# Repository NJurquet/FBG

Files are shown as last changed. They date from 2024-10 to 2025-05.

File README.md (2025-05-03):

# Fat BOTtomed Girls (FBG) - 2025 Eurobot Project




## Overview

**[Eurobot](https://www.eurobot.org/eurobot-contest/)** is an international robotics competition created in France.
The main goal of this event is to encourage youth to practice robotics with fun, by offering them an unforgettable technical and human experience.

Each year, a new theme is defined and the rules are adapted accordingly, with original actions to perform and a **100% self-made robot to build**.
Robots have to be **autonomous** and must be able to perform various tasks on a playing field in a limited amount of time to gather points.
2 teams play against each other by earning as much points as possible.
Aside from the main robot, teams can build SIMAs (Small Independent Mobile Actuator), which are small autonomous robots only living during the last 15 seconds of the match.

Project management, task sharing, autonomy, team spirit and experimentation are the core values to achieve one’s project and be ready to compete on the D-Day.

The Belgian competition was held in **Mons** and hosted by **[SparkOH!](https://sparkoh.be/projet-robotixs/robotixs/)** on April 19-20, 2025.

Have a look at our **[Wiki](https://github.com/NJurquet/FBG/wiki)** for more details about the project, team, robots, and strategy.

### Theme

The 2025 theme is **The Show Must Go On!**:

> This year the robots want to do even more competitions, more matches for more fun, but this comes with a cost.
> And in order to raise the necessary funds, some big charity concerts are planned: the Robot-Rock-Tour!
> But putting on a show is a lot of work and that’s why the robots are working extra hard to finish the preparations as quickly as possible, so that the show can take place on time.

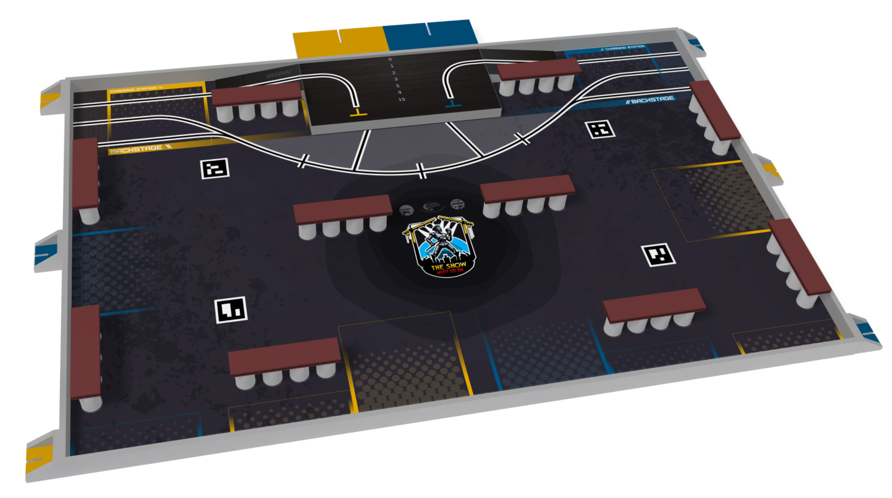
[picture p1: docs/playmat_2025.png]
Playground of the 2025 Eurobot competition


### Points

To score points, the main robot can perform the following actions:

-   **ENSURE THE PROMOTION OF THE SHOW [20 pts]**: Deploy a banner in front of the playground table.
-   **PREPARE THE CONCERT HALL**: Build tribunes of different levels (represented by 1 plank and 2 cans).
    -   [4 pts] per level 1 tribune.
    -   [8 pts] per level 2 tribune.
    -   [16 pts] per level 3 tribune.
-   **STORE TOOLS [10 pts]**: Being in the finishing area at the end of the match.
-   **ESTIMATE THE ENTRIES**: Bonus points earned by displaying an estimated score. The lower the difference between the estimated score and the real score (not counting SIMA score), the more points are earned:

    `Bonus = min(20 points - Delta/2, score done)`

SIMAs can perform the following actions:

-   [5 pts] The superstar is valid on stage at the end of the match.
-   [0, 1, 2, 3, 5, 9 or 15 pts] The superstar is close to the stage edge at the end of the match.
-   [5 pts] For each of the 3 areas of the pit occupied by at least one team groupie at the end of the match.
-   [10 pts] All SIMAs make the party (moving actuator).

## Outcome

### Qualification Round

30 teams participated in the Belgian competition, 15 being from Belgium and 15 from other countries.
The other 15 were from France and Switzerland as guests such that they can test their robots before their national competitions.

The qualification round consist of playing 4 matches against any of the teams and collecting as much cumulative points as possible.

Our team finished **4th out of the 15 Belgian teams** and **7th out of the 30 teams**.
| General Ranking | Belgian Ranking | Team Name | Team Origin | Score |
|---|---|---|---|---|
| 1 | - | Les Karibous | France | 312 |
| 2 | 1 | UCLouvain- Bot save the queen | Belgium | 307 |
| 3 | - | SUDRIABOTIK | France | 304 |
| 4 | 2 | Gramme'N Roll | Belgium | 285 |
| 5 | - | Goldorak | France | 244 |
| 6 | 3 | UCLouvain - WaltiBot | Belgium | 239 |
| **7** | **4** | **ECAM - Fat BOTtomed Girl** | **Belgium** | **238** |
| 7 | - | Coffee Machine | France | 238 |
| 9 | 5 | MonSymphony | Belgium | 235 |
| 10 | 6 | Galil'HELHa | Belgium | 180 |
| 11 | - | Robot ESEO | France | 163 |
| 12 | - | Cybernétique en Nord | France | 158 |
| 13 | - | Evolutek | France | 132 |
| 14 | - | CRENIM | France | 130 |
| 15 | 7 | ECAM - Freddie Carte Mercurie | Belgium | 124 |
| 16 | 8 | Starbot | Belgium | 118 |
| 17 | 9 | ECAM - Johnny Wall-EDay | Belgium | 99 |
| 18 | 10 | ECAM - Daft Bot's | Belgium | 92 |
| 19 | - | RTFM | Switzerland | 73 |
| 20 | - | PM-ROBOTIX | France | 71 |
| 21 | 11 | PAGACH IESN | Belgium | 50 |
| 22 | 12 | UCLouvain - Juke Bot | Belgium | 45 |
| 23 | 13 | UCLouvain - EltonBot | Belgium | 32 |
| 24 | - | TDS-Team Robotique 72 | France | 29 |
| 25 | - | E.S.C.Ro.C.S. | France | 28 |
| 26 | 14 | ECAM - Les Spice Bots | Belgium | 17 |
| 26 | 14 | UCLouvain - GOATBOT | Belgium | 17 |

### Final Round

Being in the top 8 Belgian teams, we made it to the quarter finals.
Our team faced the incredible work of **MonSymphony** who won the championship, ending our journey in the quarter finals.

Result graph of the 2025 Belgium Eurobot competition

## Project

The repository contains the code used for the SIMAs (Superstar & Groupies) in the [SIMA](./SIMA) folder and the code used for the main robot in the [BIG_BOT](./BIG_BOT) folder.

SIMAs were developed using simple `Arduino` components and coded in `C++`/`Arduino`.
The main robot was developed using a Raspberry Pi 4 to control most of the tasks, hardware, and robotic logic in `Python`.

## Installation

### Big Bot

> **Note**: It is assumed that you have a working Raspberry Pi with the OS already installed.

#### Setup & Run

1.  Clone the repository:

    ```bash
    git clone https://github.com/NJurquet/FBG.git
    cd FBG
    ```

2.  Install the Python dependencies:

    ```bash
    pip install -r requirements.txt
    ```

3.  Start the `pigpio` daemon:

    ```bash
    sudo pigpiod
    ```

4.  Run the main program:

    > Make sure every component is connected to the Raspberry Pi GPIO pins before running the program.

    ```bash
    python -m BIG_BOT.src.main --score SOME_SCORE --color YELLOW_OR_BLUE
    ```

    Replace `SOME_SCORE` with the estimated score you want to display on the LCD screen and `YELLOW_OR_BLUE` with the starting color of your robot (either `yellow` or `blue`).

    > The association between components and GPIO pins is defined in the `BIG_BOT/src/config.py` file, feel free to adapt the pins to your needs.

#### Configure Raspberry Pi as hotspot

If you want to use the Raspberry Pi as a hotspot, you will be able to access it remotely via SSH and VNC, and without the need to be connected to a Wi-Fi network (it will create its own access point).
It was especially useful during the competition for running the code on the robot remotely.

**Check [this video](https://youtu.be/TWvL2C95FEg?si=-2T3gCtMyU8DEhau) from Everyday Tech for the whole setup process and explanation.**

> [!NOTE]
> For simplicity and easy access, [RaspAP](https://raspap.com/) is used to configure the Raspberry Pi as a hotspot.
> It provides a web interface for easy configuration. For more details, visit the [RaspAP GitHub repository](https://github.com/RaspAP/raspap-webgui).
>
> If you want more control over the configuration, use `hostapd` and `dnsmasq` to set up the hotspot manually.

> [!IMPORTANT]  
> **To be able to connect the hotspot to a Wi-Fi network, you will need to have a USB Wi-Fi dongle / adapter** so the Raspberry can use its built-in Wi-Fi interface `wlan0` as the one to connect to the network and the one provided by the USB dongle `wlan1` as the hotspot.

Most of the steps are explained in the RaspAP documentation and GitHub.

1.  First, update RPi OS to its latest version, including the kernel and firmware, followed by a reboot.

    ```bash
    sudo apt-get update
    sudo apt-get full-upgrade
    sudo reboot
    ```

2.  Set the WiFi country where you plan to use the Raspberry in raspi-config's `Localisation Options`.

    ```bash
    sudo raspi-config
    ```

    > You can also enable SSH and VNC in the `Interfacing Options` menu.

3.  Install RaspAP:

    ```bash
    curl -sL https://install.raspap.com | bash
    ```

    > Note that several options to install with RaspAP will be proposed. We declined all of them as we did not need VPN, ad block or WireGuard, feel free to install them if you want.

4.  Reboot the Raspberry Pi.

    ```bash
    sudo reboot
    ```

You should now see a new Wi-Fi network called `raspi-webgui` in your available networks with this configuration:

-   **SSID**: raspi-webgui
-   **Password**: ChangeMe
-   **IP address**: 10.3.141.1
-   **DHCP range**: 10.3.141.50 — 10.3.141.254

Now you can plug the USB Wi-Fi dongle into the Raspberry Pi and check if it is recognized by the system:

```bash
lsusb
```

> [!NOTE]
> You might need to install the driver for your USB Wi-Fi dongle if it is not recognized by the system.
> Check the manufacturer's website for the driver and installation instructions.
> The best is to use a Linux compatible USB Wi-Fi dongle so this process can be skipped.

You should see the new WLAN interface `wlan1` not connected to anything and the `wlan0` used for the hotspot with:

```bash
ifconfig
```

The admin web interface can be accessed by entering the Raspberry IP address `10.3.141.1` or using its hostname `raspberrypi.local` in your web browser.
The default credentials are:

-   **Username**: admin
-   **Password**: secret

Make sure to change the default SSID and password in the `Basic` & `Security` tabs of the hotspot web interface, as well as the country code in the `Advanced` tab to the one set with `raspi-config`.

Then, in the `RaspAP` web interface, go to the `Hotspot` tab and change the interface from `wlan0` to `wlan1`, then click on `Save`.

In the Raspberry terminal, modify the `/etc/dhcpcd.conf` file by removing the the `wlan0` part so that it only uses the `wlan1` interface for the hotspot (the IP address assigned to the new `wlan1` is `10.9.141.1`):

```bash
sudo nano /etc/dhcpcd.conf
```

And remove the previous network preconfigurations with:

```bash
sudo rm /etc/NetworkManager/system-connections/preconfigured.nmconnection
sudo reboot
```

Now connect to the new hotspot and you should be able to access the web interface with correct WLANs.
Go to the `Wi-Fi client` tab to connect the `wlan0` interface to a Wi-Fi network.

> [!TIP]
> If you encounter connection or interface issues, try restarting the hotspot in the `Hotspot` tab.

### SIMA

1.  Install the Arduino IDE from the official website: [Arduino IDE](https://www.arduino.cc/en/software).

2.  Open the Arduino IDE and install the required libraries for the SIMA code:

    -   `Servo`: [link](https://docs.arduino.cc/libraries/servo/)
    -   `Adafruit Motor Shield V2 Library`: [link](https://github.com/adafruit/Adafruit_Motor_Shield_V2_Library)

3.  Adapt the pins and `groupie` & `topStartLine` configuration constants in the `SIMA/SIMA/SIMA.ino` file to your SIMA, then upload the code to your Arduino board.

    ```cpp
    // CONFIGURATION CONSTANTS ///////////////////////
    const bool groupie = true;
    const bool leftStart = digitalRead(startLeftPin);
    const bool topStartLine = false;
    const int zoneNumber = topStartLine ? 1 : 2;
    //////////////////////////////////////////////////
    ```

## License

This project is licensed under the MIT License.

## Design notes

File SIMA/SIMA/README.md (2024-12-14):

# Superstar & Groupies

## Overview

The superstar and groupies are Small Independent Mobile Actuators (SIMA) capable of navigating its environment while avoiding obstacles. They both have specific roles but they use an ultrasonic sensor to detect obstacles, IR sensors to follow lines drawn on the table, Bluetooth module for remote debugging and a finite state machine (FSM) to manage its states and behaviors.

## Depedencies

-   `Adafruit Motor Shield V2 Library` : v1.1.3

## Components

-   **Arduino Uno**: The microcontroller used to control the robot.
-   **Adafruit Motor Shield V2**: Used to control the motors of the robot.
-   **Ultrasonic Sensor HC-SR04**: Used to detect obstacles in the robot's path.
-   **IR sensor**: Used to follow lines drawn on the table.
-   **HC-05 Bluetooth module** : Used to debug robot actions.

## Setup

### Hardware Setup

-   **Motors** : First, place the motor shield on the Arduino. Then, connect the left motor to `M4`, and the right motor to `M3`.
-   **Ultrasonic sensor** : Connect the VCC to `5V`, GND to `GND`, Trig to pin `11`, and Echo to pin `12`.
-   **IR sensors** : Connect the VCC to `5V`, GND to `GND`, and the left sensor to pin `A0` and the right sensor to pin `A1`.
-   **Bluetooth** : Connect the VCC to `5V`, GND to `GND`, RX to pin `10`, and TX to pin `9`.

### Software Setup

-   Open Arduino IDE and install the necessary libraries (e.g., Adafruit Motor Shield V2 library).
-   Open the `.ino` file (`.cpp` and `.h` files should open automatically).
-   Build & upload the code to the Arduino.

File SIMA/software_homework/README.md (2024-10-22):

# Superstar & Groupies

## Overview

The superstar and groupies are Small Independent Mobile Actuators (SIMA) capable of navigating its environment while avoiding obstacles. They both have specific roles but they use an ultrasonic sensor to detect obstacles, IR sensors to follow lines drawn on the table and a finite state machine (FSM) to manage its states and behaviors.

## Depedencies

-   `Adafruit Motor Shield V2 Library`

## Components

-   **Arduino Uno**: The microcontroller used to control the robot.
-   **Adafruit Motor Shield V2**: Used to control the motors of the robot.
-   **Ultrasonic Sensor HC-SR04**: Used to detect obstacles in the robot's path.
-   **IR sensor**: Used to follow lines drawn on the table.

## Setup

1. **Hardware Setup**:

    - Connect the ultrasonic sensor to the specified pins on the Arduino.
    - Connect the IR sensors to the specified pins on the Arduino.
    - Connect the motors to the Adafruit Motor Shield V2.
    - Attach the Motor Shield to the Arduino.

2. **Software Setup**:
    - Install the necessary libraries (e.g., Adafruit Motor Shield library).
    - Build & upload the code to the Arduino.

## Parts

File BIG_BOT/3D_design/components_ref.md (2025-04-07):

# Big Bot Assembly

This is a description of the components used for the **Big Bot** project, including the motor, sensors, and accessories.

## Components

### 1. **Servo Motor: MG996R**
The **MG996R** is a high-torque servo motor, suitable for precise control in various robotic applications. It provides powerful rotation, ideal for applications requiring motion and positioning.

### 2. **Emergency Button: A01ES-DM + A0154B-D + A01YL1**
The **A01ES-DM** emergency button system allows for quick and reliable activation of emergency stops in critical applications. It ensures safety in the event of a failure or unexpected behavior in the system.

### 3. **Aluminum Profiles: MakerBeamXL - 15x15mm**
These aluminum profiles are used for the structural framework of the bot. With the **MakerBeamXL** 15x15mm profiles, you get a lightweight, durable, and customizable structure that is easy to assemble.

### 4. **Raspberry Pi 4**
The **Raspberry Pi 4** serves as the brain of the Big Bot. With its quad-core processor, powerful GPU, and ample RAM, the Raspberry Pi 4 can handle a variety of robotic tasks, from control to data processing.

### 5. **12V Motors: 37D Metal Gearmotors**
The **37D Metal Gearmotors** are robust motors perfect for driving the movement of the bot. With their durable metal gears and high torque, these motors can drive heavy loads and work reliably in various robotic setups.

### 6. **Ultrasonic Sensors: HC-SR04**
The **HC-SR04** ultrasonic sensors provide precise distance measurements, helping the bot navigate its environment. With its simple interface and accurate range, it's a perfect sensor for obstacle detection and avoidance.

### 7. **Ball Caster: LEZED L176**
The **LEZED L176** ball caster is a small but essential part of the Big Bot, providing a stable rolling point for easy movement. It ensures smooth navigation and stability for mobile robots.

### 8. **LCD Display: AZDelivery HD44780 2004**
The **AZDelivery HD44780 2004** LCD display is used for showing important information and status updates. With its clear, readable display, it serves as an interface for diagnostics and control feedback.

### 9. **DC-DC Step Down Buck Converter: AZDelivery XL4016E1**
The **AZDelivery XL4016E1** step-down buck converter allows for efficient voltage conversion. It steps down the input voltage (from 12V to 5V) to power the Raspberry Pi and other components of the Big Bot.

### 10. **3D-Printed Parts**
In addition to the listed components, several parts of the **Big Bot** were 3D-printed for custom structures, mounting solutions, and other specialized components. These parts help reduce weight and offer a high degree of customization.

## Conclusion

This is the collection of key components that form the **Big Bot**. Each part plays a crucial role in ensuring functionality, reliability, and ease of customization. Whether for movement, sensing, or interaction, these components work together to bring the robot to life.

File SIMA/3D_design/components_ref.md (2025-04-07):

# Super Star & Groupies Bots Assembly

This document outlines the components used in the **Super Star** and **Groupies Bots** projects, covering motors, sensors, and other essential accessories.

## Components

### 1. **Emergency Button: A01ES-DM + A0154B-D + A01YL1**
The **A01ES-DM** emergency button system ensures quick and reliable activation of emergency stops in critical applications. It provides an essential safety feature for the bot, preventing malfunction or unexpected behavior by enabling immediate system shutdown.

### 2. **Ultrasonic Sensors: HC-SR04**
The **HC-SR04** ultrasonic sensors are crucial for measuring distances and enabling the bots to navigate their surroundings. With their easy integration and accurate range, these sensors are perfect for obstacle detection and avoidance.

### 3. **3D-Printed Parts**
Several parts of the **Super Star** and **Groupies Bots** were 3D-printed to meet specific design requirements. These custom structures, mounting solutions, and other components offer reduced weight, greater flexibility, and enhanced customization options.

### 4. **IR Sensor: Frienda-Obstacle-431S**
The **Frienda-Obstacle-431S** infrared sensor aids in detecting obstacles around the bot by emitting infrared light and measuring the reflection. This sensor is ideal for proximity sensing and works well in conjunction with the ultrasonic sensors to improve navigation and decision-making.

### 5. **Servo Motor: MS18**
The **MS18** servo motor provides high precision and reliable movement for the **Super Star** and **Groupies Bots**. It's designed to deliver smooth motion and control in applications where accuracy and positioning are essential.

### 6. **Arduino Uno**
The **Arduino Uno** acts as the central controller for both the **Super Star** and **Groupies Bots**. With its open-source platform, the Arduino Uno is perfect for prototyping and programming, offering a simple yet powerful foundation for building and controlling robots.

### 7. **DFRobot MiniQ 2WD - 2 Wheel Robot Chassis with DC Motor Drive**
The **DFRobot MiniQ 2WD** chassis is designed for building compact two-wheel-drive robots. It's equipped with DC motors, making it ideal for mobile robots that require agile movement and easy control. The chassis provides a solid foundation for building both the **Super Star** and **Groupies Bots**.

### 8. **Feetech FT-DC-002-KIT - Aluminium 2WD Robot Chassis**
The **Feetech FT-DC-002-KIT** is another two-wheel-drive chassis used in the **Groupies Bots** project. Constructed from durable aluminum, this chassis offers lightweight performance while maintaining strength, making it a perfect platform for building versatile robots.

## Conclusion

The **Super Star** and **Groupies Bots** are assembled from a carefully selected set of components, each chosen for its functionality, durability, and compatibility. Whether for movement, sensing, or interaction, these parts come together to create highly adaptable and customizable robots ready to take on any challenge.

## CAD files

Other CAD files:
SIMA/3D_design/super_star/assembly/assembly_super_star.step
SIMA/3D_design/groupie/stl/emergency_button_holder_mainpart.step
BIG_BOT/3D_design/assembly/big_bot.step
BIG_BOT/3D_design/stl/lcd_frame.stl
SIMA/3D_design/groupie/assembly/groupie.step
SIMA/3D_design/groupie/stl/emergency_button_holder_subpart.step
SIMA/3D_design/super_star/stl/capot_cover.step
BIG_BOT/3D_design/stl/caster_holder.stl
SIMA/3D_design/super_star/stl/ultrasonic_ir_sensors_holder.step
BIG_BOT/3D_design/stl/foldable_fork.stl
SIMA/3D_design/groupie/stl/carrosserie.step
SIMA/3D_design/super_star/stl/servo_celebration_module.step
BIG_BOT/3D_design/stl/side_claw_servo_structure.stl
SIMA/3D_design/groupie/stl/battery_holder.step
SIMA/3D_design/super_star/stl/carrosserie.step
BIG_BOT/3D_design/stl/center_claw.stl
SIMA/3D_design/groupie/stl/upper_chassis.step
SIMA/3D_design/super_star/stl/upper_chassis.step
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

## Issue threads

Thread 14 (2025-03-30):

Bug: gpiozero.DistanceSensor Blocking Code with DistanceSensorNoEcho Warning

NJurquet, 2025-03-30:
### Bug Description
When trying to get the distance with `gpiozero.DistanceSensor` as an HC-SR04 ultrasonic sensor, the warning `warnings.warn(DistanceSensorNoEcho('no echo received'))` appears. This warning seems to block further execution of the code.
We have used a Raspberry Pi 4B running on `Python 3.12`.
Interestingly, all unit tests using Mocks pass without issues, meaning the problem only occurs with actual hardware.
Bug is most problably due to #13 PR.

### Steps to Reproduce
1. Connect an HC-SR04 ultrasonic sensor to a Raspberry Pi with trigger and echo pin connected. Echo placed in a voltage divider.
2. Initialize the `DistanceSensor` in a Python script using `gpiozero`.
3. Attempt to read the distance measurement with `DistanceSensor.distance`.
4. Run script

### Expected Behavior
- The `DistanceSensor` should return the distance.
- The warning should be non-blocking and allow the rest of the script to continue running even if no echo is received.

### Actual Problem
The following code triggers the issue:

```python
# ultrasonicSensor.py
class UltrasonicSensor:
    def getDistance(self) -> float:
        """
        Returns the distance measured in centimeters.

        Returns:
            float: The distance in centimeters.
        """
        return self._sensor.distance * 100

# ultrasonicController.py
class UltrasonicController:
    def add_sensor(self, pos: USPosition, echoPin: int, trigPin: int) -> None:
        """
        Add a new ultrasonic sensor to the controller.

        Parameters:
            `pos` (USPosition): The position of the sensor.
            `echoPin` (int): The GPIO pin connected to the sensor's echo pin.
            `trigPin` (int): The GPIO pin connected to the sensor's trigger pin.
        """
        ...

        if any(sensor.pos == pos for sensor in self._sensors):
            raise ValueError(f"Sensor with position {pos} already exists in the controller.")
        self._sensors.append(UltrasonicSensor(pos, echoPin, trigPin))

# robot.py
class Robot:
    def __init__(self):
        self.ultrasonicController = UltrasonicController()
        self.ultrasonicController.add_sensor(USPosition.FRONT_RIGHT, US_FRONT_RIGHT_ECHO_PIN, US_FRONT_RIGHT_TRIG_PIN)
        self.ultrasonicController.add_sensor(USPosition.FRONT_LEFT, US_FRONT_LEFT_ECHO_PIN, US_FRONT_LEFT_TRIG_PIN)

# config.py
## Ultrasonic Sensors Pins ##
US_FRONT_RIGHT_TRIG_PIN = 7
US_FRONT_RIGHT_ECHO_PIN = 8

US_FRONT_LEFT_TRIG_PIN = 20
US_FRONT_LEFT_ECHO_PIN = 21
```
Output:
```
/usr/lib/python3/dist-packages/gpiozero/input_devices.py:1382: DistanceSensorNoEcho: no echo received
  warnings.warn(DistanceSensorNoEcho('no echo received'))
```

### Additional notes
- The issue occurs in real hardware but does not appear in unit tests using Mocks.
- It is unclear whether this is a bug in software or related to hardware like the voltage divider.

NJurquet, 2025-03-31:
Everything mentionned in this comment was commited on the `sprint_2` branch.

### DistanceSensorNoEcho warning
I've just tested the ultrasonic sensors by connecting correct pins to the Raspberry and everything was working correctly when running `ultrasonicController` or `ultrasonicSensor` except that the distance is wrong.
```python
# ultrasonicSensor.py
if __name__ == "__main__":
    import time
    us_sensor = UltrasonicSensor(USPosition.FRONT_RIGHT, 7, 8)
    while True:
        print(f"Distance: {us_sensor.getDistance():.2f} cm")
        time.sleep(1)
```

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
I've tested the same sensor on an Arduino and same result so this sensor is actually deficient.

Also when removing the trigger or echo pin from the Raspberry, the `no echo received` warning was thrown:
```
/home/ecam/.local/lib/python3.12/site-packages/gpiozero/input_devices.py:975: DistanceSensorNoEcho: no echo received
  warnings.warn(DistanceSensorNoEcho('no echo received'))
```
This **echo problem is still blocking execution of the code** even when catching warnings with `with warnings.catch_warnings()` and `warnings.simplefilter("ignore")` as the warning is only a "print". I couldn't find any solution for this except from not having that warning by having all working hardware.

**So this issue is a *hardware* problem most certainly cause by wrong wiring, short-circuits or voltage divider on echo pin.**

### PWMSoftwareFallback warning
When using the default pin factory for the ultrasonic sensor, it always give a warning that we should use `pigpio` and that this library is more accurate:
```
/home/ecam/.local/lib/python3.12/site-packages/gpiozero/input_devices.py:852: PWMSoftwareFallback: For more accurate readings, use the pigpio pin factory.See https://gpiozero.readthedocs.io/en/stable/api_input.html#distancesensor-hc-sr04 for more info
  warnings.warn(PWMSoftwareFallback(
```
So I've added the `PiGPIOFactory` as the factory to use and works perfectly. **Note that it required to run `sudo pigpiod` to start the daemon with root privileges**.

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

I've also managed problems occuring when we are testing the code on Windows or when runing tests on GitHub Actions by using dynamic import of the factory. `pigpio` is only working on Raspberry, so if we are running the project in another OS / environment, it will use the default pin factory that was working before.
```python
# ultrasonicSensor.py
import os
import platform
from gpiozero import DistanceSensor, Pin
if os.getenv("GITHUB_ACTIONS") == "true" or platform.system() == "Windows":
    factory = None
else:
    try:
        from gpiozero.pins.pigpio import PiGPIOFactory
        factory = PiGPIOFactory()
    except OSError:
        factory = None
from ..constants import USPosition

...

    def __init__(self, pos: USPosition, echoPin: int, trigPin: int):
        self._sensor = DistanceSensor(echo=echoPin, trigger=trigPin, max_distance=1, pin_factory=factory)
```

NJurquet, 2025-04-01:
So I confirm ultrasonic sensors are working, as well as the ultrasonic controller code. I've connected the trigger/echo pins to the same pins defined in `config.py` (which were the same used during sprint 2).

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

Distances measured are of correct values and the event triggered is working well : No event when distances < 20cm, obstacle detected when detecting a new one, and obstacle present when continuously detecting the same obstacle.

As it works as intended I close this issue.

Closed 2025-04-01.

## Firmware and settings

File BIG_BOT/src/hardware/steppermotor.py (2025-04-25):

from gpiozero import DigitalOutputDevice, Button
from ..utils import precise_sleep


class StepperMotor:
    """
    Interfaces with a NEMA stepper via an A4988 driver.

    The following pins are used:
      - step: pulses for each step.
      - dir: controls direction (clockwise or counter-clockwise).
      - MS1, MS2, MS3: define the microstepping resolution.

    Limit switches:
      - Optionally, you can provide top_limit_pin and bottom_limit_pin.
        These are used for homing and safe operation to stop rotation
        when a mechanical limit is reached.

    Microstepping settings supported (resolution: multiplier):
      - 1    → Full step    (MS1=LOW, MS2=LOW, MS3=LOW)    → 200 steps/rev
      - 1/2  → Half step    (MS1=HIGH, MS2=LOW, MS3=LOW)   → 400 steps/rev
      - 1/4  → Quarter step (MS1=LOW, MS2=HIGH, MS3=LOW)   → 800 steps/rev
      - 1/8  → Eighth step  (MS1=HIGH, MS2=HIGH, MS3=LOW)  → 1600 steps/rev
      - 1/16 → Sixteenth    (MS1=HIGH, MS2=HIGH, MS3=HIGH) → 3200 steps/rev (if supported)

    A simple position tracking (in steps) is implemented so that after homing the vertical position can be monitored and controlled.

    **Note:** The reset and sleep pins on your A4988 are assumed to be wired together to keep the stepper motor at full power.
    """

    # Microstepping mapping: resolution → (MS1, MS2, MS3)
    _MICROSTEP_RESOLUTION = {
        1:  (0, 0, 0),
        2:  (1, 0, 0),
        4:  (0, 1, 0),
        8:  (1, 1, 0),
        16: (1, 1, 1),
    }
    _BASE_STEPS_PER_REV = 200  # Full step base (1.8° per step)

    def __init__(self, step: int, dir: int, ms1: int, ms2: int, ms3: int,
                 step_delay: float = 0.002, microstep: int = 1,
                 top_limit_pin: int | None = None, bottom_limit_pin: int | None = None):
        """
        Initialize the stepper motor and, optionally, limit switches.

        Parameters:
            `step` (int):   GPIO pin for STEP.
            `dir` (int):    GPIO pin for DIR.
            `ms1` (int):  GPIO pin for MS1.
            `ms2` (int):  GPIO pin for MS2.
            `ms3` (int):  GPIO pin for MS3.
            `step_delay` (float): Delay between high and low transitions (in seconds), default is 0.002s. Step delay must be higher or equal to 0.002s.
            `microstep` (int): Number of microsteps to perform per full step, default is 1. The corresponding microstepping resolution is (1, 1/2, 1/4, 1/8, 1/16).
            `top_limit_pin` (int): Optional GPIO pin for the top limit switch, default is None.
            `bottom_limit_pin` (int): Optional GPIO pin for the bottom limit switch, default is None.
        """
        # Create gpiozero devices for A4988 control.
        self._step_device = DigitalOutputDevice(step)
        self._dir_device = DigitalOutputDevice(dir)
        self._ms1_device = DigitalOutputDevice(ms1)
        self._ms2_device = DigitalOutputDevice(ms2)
        self._ms3_device = DigitalOutputDevice(ms3)
        try:
            self._top_switch = Button(top_limit_pin) if top_limit_pin is not None else None
            self._bottom_switch = Button(bottom_limit_pin) if bottom_limit_pin is not None else None
        except ValueError as e:
            self._top_switch = None
            self._bottom_switch = None
            import warnings
            warnings.warn(f"Top or bottom limit switches are invalid or not connected.\nError: {e}", stacklevel=2)
        precise_sleep(0.001)

        if step_delay < 0.002:
            raise ValueError("step_delay must be >= 0.002 seconds.")
        self._step_delay = step_delay
        self._current_resolution = microstep
        self._steps_per_rev = self._BASE_STEPS_PER_REV * microstep
        self.set_microstepping(self._current_resolution)

        self.current_position: int | None = None  # Vertical position in steps (None until homed).

        self.stop_flag = False  # Call this Flag to stop the motor.

    def set_microstepping(self, resolution: int) -> None:
        """
        Set the microstepping resolution to apply on MS1, MS2, MS3 pins.

        Parameters:
            `resolution` (int): The resolution to set, one of (1, 2, 4, 8, 16).
                - 1: Full step (200 steps/rev).
                - 2: Half step (400 steps/rev).
                - 4: Quarter step (800 steps/rev).
                - 8: Eighth step (1600 steps/rev).
                - 16: Sixteenth step (3200 steps/rev).
        Raises:
            `ValueError`: If the resolution is unsupported.
        """
        if resolution not in self._MICROSTEP_RESOLUTION:
            raise ValueError(f"Unsupported resolution: {resolution}. Choose from {list(self._MICROSTEP_RESOLUTION.keys())}")
        ms1_state, ms2_state, ms3_state = self._MICROSTEP_RESOLUTION[resolution]
        self._ms1_device.on() if ms1_state else self._ms1_device.off()
        self._ms2_device.on() if ms2_state else self._ms2_device.off()
        self._ms3_device.on() if ms3_state else self._ms3_device.off()
        self._current_resolution = resolution
        self._steps_per_rev = self._BASE_STEPS_PER_REV * resolution

    @property
    def steps_per_rev(self) -> int:
        """Return the full number of steps per revolution, including the current microstepping resolution."""
        return self._steps_per_rev

    def step(self, steps: int, clockwise: bool = False, update_position: bool = True) -> None:
        """
        Pulse the STEP pin a specific number of times to rotate the motor by a given number of steps.
        The direction is controlled by the DIR pin.

        Parameters:
            `steps` (int): Number of steps to move (absolute count).
            `clockwise` (bool): Direction flag, default is False. Clockwise rotation increases vertical position.
            `update_position` (bool): If True and if current_position is set, update the internal position count.
        """
        self._dir_device.value = clockwise  # Set direction.
        for _ in range(abs(steps)):
            if self.stop_flag:
                print("Stepper Motor stopped.")
                break

            self._step_device.on()
            precise_sleep(self._step_delay)  # Precise sleep to avoid timing issues.
            self._step_device.off()
            precise_sleep(self._step_delay)  # Precise sleep to avoid timing issues.
            if update_position and self.current_position is not None:
                self.current_position += 1 if clockwise else -1

    def rotate(self, rotations: float, clockwise: bool = True) -> None:
        """
        Rotate the motor a specific number of rotations (full or fractional).

        Parameters:
            `rotations` (float): Number of full or fractional rotations.
            `clockwise` (bool): Direction of rotation, default is True. Clockwise rotation increases vertical position.
        """
        total_steps = int(self._steps_per_rev * rotations)
        print(f"Rotating {rotations} rotations ({total_steps} steps) {'clockwise' if clockwise else 'counter-clockwise'}.")
        self.step(total_steps, clockwise=clockwise, update_position=True)

    def home_bottom(self) -> None:
        """
        Move the motor downward until the bottom limit switch is triggered.
        After homing, the vertical position is set to 0.

        Raises:
            `Exception`: If the bottom limit switch is not configured.
        """
        if self._bottom_switch is None:
            raise Exception("Bottom limit switch not configured.")
        while not self._bottom_switch.is_active:
            if self.stop_flag:
                print("Stepper Motor stopped.")
                break

            self.step(1, clockwise=False, update_position=False)
        self.current_position = 0
        print("Homed: bottom limit reached. Current position set to 0.")

    def move_to_top(self) -> None:
        """
        Step upward one step at a time until the top limit switch is activated.
        Updates the current position as it moves.

        Raises:
            `Exception`: If the top limit switch is not configured.
        """
        if self._top_switch is None:
            raise Exception("Top limit switch not configured.")
        while not self._top_switch.is_active:
            if self.stop_flag:
                print("Stepper Motor stopped.")
                break

            self.step(1, clockwise=True, update_position=True)
        print("Reached top limit.")

    def move_to_bottom(self):
        """
        Step downward one step at a time until the bottom limit switch is activated.
        Updates the current position as it moves.

        Raises:
            `Exception`: If the bottom limit switch is not configured.
        """
        if self._bottom_switch is None:
            raise Exception("Bottom limit switch not configured.")
        while not self._bottom_switch.is_active:
            if self.stop_flag:
                print("Stepper Motor stopped.")
                break

            self.step(1, clockwise=False, update_position=True)
        print("Reached bottom limit.")
        self.current_position = 0

    def move_to_position(self, target_position: int) -> None:
        """
        Move the motor one step at a time to a target vertical position.
        Current position is tracked in steps. It is assumed that the motor has been homed,
        so current_position is not None.

        Parameters:
            `target_position` (int): The desired vertical position in step counts.

        Raises:
            `Exception`: If current_position is undefined (None).
        """
        if self.current_position is None:
            raise Exception("Current position is undefined. Please home the motor first.")

        print(f"Moving from position {self.current_position} to target {target_position}.")
        while abs(self.current_position - target_position) > 0:
            if self.stop_flag:
                print("Stepper Motor stopped.")
                break

            # If going upward, check if top limit is reached.
            if self.current_position < target_position:
                if self._top_switch is not None and self._top_switch.is_active:
                    print("Top limit reached; cannot move further upward.")
                    break
                self.step(1, clockwise=True, update_position=True)
            # If going downward, check if bottom limit is reached.
            elif self.current_position > target_position:
                if self._bottom_switch is not None and self._bottom_switch.is_active:
                    print("Bottom limit reached; cannot move further downward.")
                    break
                self.step(1, clockwise=False, update_position=True)
        print(f"Target reached. Current position: {self.current_position}")

    def cleanup(self) -> None:
        """
        Clean up all gpiozero stepper devices.
        """
        self._step_device.close()
        self._dir_device.close()
        self._ms1_device.close()
        self._ms2_device.close()
        self._ms3_device.close()
        if self._top_switch:
            self._top_switch.close()
        if self._bottom_switch:
            self._bottom_switch.close()

    def stop(self) -> None:
        """
        Stop the motor immediately by setting the stop flag.
        """
        self.stop_flag = True
        print("Stepper Motor stop flag set.")


if __name__ == '__main__':
    from ..config import STEPPER_DIR_PIN, STEPPER_STEP_PIN, STEPPER_MS1_PIN, STEPPER_MS2_PIN, STEPPER_MS3_PIN, STEPPER_BOTTOM_LIMIT_PIN, STEPPER_TOP_LIMIT_PIN
    from gpiozero import Device
    from gpiozero.pins.mock import MockFactory
    Device.pin_factory = MockFactory()

    stepper = StepperMotor(step=STEPPER_STEP_PIN, dir=STEPPER_DIR_PIN,
                           ms1=STEPPER_MS1_PIN, ms2=STEPPER_MS2_PIN, ms3=STEPPER_MS3_PIN,
                           step_delay=0.005, microstep=1,
                           top_limit_pin=STEPPER_TOP_LIMIT_PIN, bottom_limit_pin=STEPPER_BOTTOM_LIMIT_PIN)

    try:
        # Home the motor at the bottom.
        # stepper.home_bottom()

        # Now, move until the top limit is reached.
        # stepper.move_to_top()

        # Move to a target position of 1000 steps (if within the allowed range).
        # stepper.move_to_position(target_position=1000)

        stepper.rotate(rotations=4, clockwise=True)

    finally:
        # Always clean up the devices.
        stepper.cleanup()

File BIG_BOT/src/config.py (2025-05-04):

"""
config.py

This module contains all configuration constants used throughout the project.
It serves as a centralized location for managing settings and values that are used in multiple parts of the project.
Change these config constants to customize the behavior of the robot.
"""

# ===================================================================
# Hardware Pins Configuration
# ===================================================================

## I2C Bus Pins ##
I2C_DATA_PIN = 2
I2C_CLOCK_PIN = 3

## Motor Pins ##

LEFT_MOTOR_FORWARD_PIN = 17
LEFT_MOTOR_BACKWARD_PIN = 27
LEFT_MOTOR_EN_PIN = 18  # PWM

RIGHT_MOTOR_FORWARD_PIN = 5
RIGHT_MOTOR_BACKWARD_PIN = 6
RIGHT_MOTOR_EN_PIN = 19  # PWM

# Motor driver to motor connection :
#   - OUT 1 -> Left motor red pin
#   - OUT 2 -> Left motor black pin
#   - OUT 3 -> Right motor red pin
#   - OUT 4 -> Right motor black pin

## Stepper Motor NEMA pins ##
STEPPER_DIR_PIN = 4
STEPPER_STEP_PIN = 22
STEPPER_MS1_PIN = 10
STEPPER_MS2_PIN = 9
STEPPER_MS3_PIN = 11
# STEPPER_BOTTOM_LIMIT_PIN = 0
# STEPPER_TOP_LIMIT_PIN = 1

STEPPER_MIDDLE_POINT = 600 # Steps to go to be in the middle of the belt

# Adafruit Servo Controller Channels
SERVO_CHANNELS = 16

## Servo Claws ##
CENTER_RIGHT_CLAW_NAME = "centerRightClaw"
CENTER_LEFT_CLAW_NAME = "centerLeftClaw"
OUTER_RIGHT_CLAW_NAME = "outerRightClaw"
OUTER_LEFT_CLAW_NAME = "outerLeftClaw"
CENTER_RIGHT_CLAW_ADAFRUIT_PIN = 0
CENTER_LEFT_CLAW_ADAFRUIT_PIN = 1
OUTER_RIGHT_CLAW_ADAFRUIT_PIN = 2
OUTER_LEFT_CLAW_ADAFRUIT_PIN = 3

BANNER_DEPLOYER_IDLE = 30
BANNER_DEPLOYER_DEPLOY_STAGE_1 = 80
BANNER_DEPLOYER_DEPLOY_STAGE_2 = 150

## Servo PlankPushers ##
PLANK_PUSHER_RIGHT_NAME = "plankPusherRight"
PLANK_PUSHER_LEFT_NAME = "plankPusherLeft"
PLANK_PUSHER_RIGHT_ADAFRUIT_PIN = 4
PLANK_PUSHER_LEFT_ADAFRUIT_PIN = 5

## Servo Banner Deployer ##
BANNER_DEPLOYER_NAME = "bannerDeployer"
BANNER_DEPLOYER_ADAFRUIT_PIN = 7

## Ultrasonic Sensors Pins ##
US_FRONT_RIGHT_TRIG_PIN = 7
US_FRONT_RIGHT_ECHO_PIN = 8

US_FRONT_MIDDLE_TRIG_PIN = 0
US_FRONT_MIDDLE_ECHO_PIN = 1

US_FRONT_LEFT_TRIG_PIN = 20
US_FRONT_LEFT_ECHO_PIN = 21

US_BACK_RIGHT_TRIG_PIN = 16
US_BACK_RIGHT_ECHO_PIN = 25

US_BACK_LEFT_TRIG_PIN = 23
US_BACK_LEFT_ECHO_PIN = 24

US_CENTER_RIGHT_TRIG_PIN = 13
US_CENTER_RIGHT_ECHO_PIN = 14

US_CENTER_LEFT_TRIG_PIN = 12
US_CENTER_LEFT_ECHO_PIN = 15

# Reed Switch Pin
REED_SWITCH_PIN = 26

# ===================================================================
# Servo Configuration
# ===================================================================

## Servo Claws angles lists ##
ALL_OPEN = [150, 150, 150, 150]
SERVO_IDLE = [150, 150, 50, 60]
SERVO_INIT = [150, 150, 60, 150]
ALL_CLOSED = [90, 90, 70, 90]
OUTER_OPEN = [150, 150]
OUTER_INIT = [60, 150]

PLANK_PUSHER_BLOCKING = [10, 70]
PLANK_PUSHER_MIDDLE = [10, 150]
PLANK_PUSHER_INIT = [180, 40]
PLANK_PUSHER_PUSH = [30, 180]

# ===================================================================
# Robot Configuration
# ===================================================================

DEFAULT_SCORE = 30
"""Default score for the robot if nothing is passed as command line argument."""

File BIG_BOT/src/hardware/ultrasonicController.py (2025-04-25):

from .ultrasonicSensor import UltrasonicSensor
from ..constants import USPosition, USEvent


class UltrasonicController:
    """
    Class managing multiple ultrasonic sensors.

    Parameters:
        `sensorsDict` (dict[USPosition, tuple[int, int]]): A dictionary where each key is the position of a sensor and the value is a tuple with the echo and trigger pins.
    """

    def __init__(self):
        self._sensors: list[UltrasonicSensor] = []
        self._last_obstacle: bool = False
        self._distances: dict[USPosition, float] = {}
        self._enabled_sensors: dict[USPosition, bool] = {}


    def add_sensor(self, pos: USPosition, echoPin: int, trigPin: int) -> None:
        """
        Add a new ultrasonic sensor to the controller.

        Parameters:
            `pos` (USPosition): The position of the sensor.
            `echoPin` (int): The GPIO pin connected to the sensor's echo pin.
            `trigPin` (int): The GPIO pin connected to the sensor's trigger pin.
        """
        if not isinstance(pos, USPosition):
            raise TypeError(f"Expected pos to be of type USPosition, got {type(pos).__name__}.")
        if not isinstance(echoPin, int) or not isinstance(trigPin, int):
            raise TypeError("echoPin and trigPin must be integers.")
        if echoPin < 0 or trigPin < 0 or echoPin == trigPin:
            raise ValueError("echoPin and trigPin must be positive integers and not equal.")

        if any(sensor.pos == pos for sensor in self._sensors):
            raise ValueError(f"Sensor with position {pos} already exists in the controller.")
        self._sensors.append(UltrasonicSensor(pos, echoPin, trigPin))
        self._enabled_sensors[pos] = True


    def enable_sensor(self, pos: USPosition) -> None:
        """
        Enable the ultrasonic sensor at the specified position.

        Parameters:
            `pos` (USPosition): The position of the sensor.
        """
        if pos in self._enabled_sensors:
            self._enabled_sensors[pos] = True
        else:
            print(f"Tried to enable sensor at position {pos}, but was not in the list of enabled sensors.")

    def disable_sensor(self, pos: USPosition) -> None:
        """
        Disable the ultrasonic sensor at the specified position.

        Parameters:
            `pos` (USPosition): The position of the sensor.
        """
        if pos in self._enabled_sensors:
            self._enabled_sensors[pos] = False
        else:
            print(f"Tried to disable sensor at position {pos}, but was not in the list of enabled sensors.")

    def toggle_sensor(self, pos: USPosition) -> None:
        """
        Toggle the ultrasonic sensor at the specified position.

        Parameters:
            `pos` (USPosition): The position of the sensor.
        """
        if pos in self._enabled_sensors:
            self._enabled_sensors[pos] = not self._enabled_sensors[pos]
        else:
            print(f"Tried to toggle sensor at position {pos}, but was not in the list of enabled sensors.")
    
    def check_obstacles(self) -> USEvent:
        """
        Check if any of the ultrasonic sensors detects an obstacle.
        Make sure to call `measure_distances()` before calling this method.

        Returns:
            `USEvent`: The event that occurred.
            - `OBSTACLE_DETECTED`: If a new obstacle is detected.
            - `OBSTACLE_PRESENT`: If the same obstacle is still detected.
            - `OBSTACLE_CLEARED`: If the previously detected obstacle is no longer detected.
            - `NO_EVENT`: If no obstacle is detected.
        """
        # If no sensors provided or no distances measured
        if len(self._sensors) == 0 or len(self._distances) == 0:
            return USEvent.NO_EVENT
        
        # Define which positions are considered "front" sensors
        front_positions = [USPosition.FRONT_LEFT, USPosition.FRONT_MIDDLE, USPosition.FRONT_RIGHT]
        side_positions = [USPosition.CENTER_LEFT, USPosition.CENTER_RIGHT]
        back_positions = [USPosition.BACK_LEFT, USPosition.BACK_RIGHT]
    
        # Check if any enabled front sensor detects an obstacle within 25cm
        front_obstacle_detected = any(
            self._distances.get(pos, float('inf')) < 32
            for pos in front_positions
            if pos in self._enabled_sensors and self._enabled_sensors[pos]
        )

        side_obstacle_detected = any(
            self._distances.get(pos, float('inf')) < 8
            for pos in side_positions
            if pos in self._enabled_sensors and self._enabled_sensors[pos]
        )

        back_obstacle_detected = any(
            self._distances.get(pos, float('inf')) < 10
            for pos in back_positions
            if pos in self._enabled_sensors and self._enabled_sensors[pos]
        )
        
        # An obstacle is detected if either front or other sensors detect an obstacle
        obstacle_detected = front_obstacle_detected or side_obstacle_detected or back_obstacle_detected
        
        if obstacle_detected:
            # If the obstacle was not detected before
            if not self._last_obstacle:
                self._last_obstacle = True
                return USEvent.OBSTACLE_DETECTED
            return USEvent.OBSTACLE_PRESENT  # Still detecting the same obstacle
        else:
            # If the previously detected obstacle is no longer in range
            if self._last_obstacle:
                self._last_obstacle = False
                return USEvent.OBSTACLE_CLEARED
    
        # If no obstacle detected
        return USEvent.NO_EVENT
    
    def get_enabled_sensors(self) -> dict[USPosition, bool]:
        """
        Get the enabled sensors.

        Returns:
            dict[USPosition, bool]: A dictionary of enabled sensors.
        """
        return self._enabled_sensors

    def measure_distances(self) -> None:
        """
        Measure distances from all ultrasonic sensors.
        """
        self._distances = {sensor.pos: sensor.getDistance() for sensor in self._sensors
                           if self._enabled_sensors[sensor.pos]}

    def get_distance(self, pos: USPosition) -> float:
        """
        Get the measured distance from the specified ultrasonic sensor.

        Parameters:
            `pos` (USPosition): The position of the sensor.

        Returns:
            float: The distance in centimeters.

        Raises:
            ValueError: If the specified position does not correspond to any sensor.
        """
        if not isinstance(pos, USPosition):
            raise TypeError(f"Expected pos to be of type USPosition, got {type(pos).__name__}.")
        for sensor in self._sensors:
            if sensor.pos == pos:
                return sensor.getDistance()
        raise ValueError(f"No sensor found with position {pos}.")
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

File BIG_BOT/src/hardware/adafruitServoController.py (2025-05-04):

from adafruit_servokit import ServoKit

class AdafruitServoControl:
    """
        Class to control multiple servo motors using PCA9685
        The I2C connection is automatically initialized by the Adafruit ServoKit library.

        Parameters:
            channels (int): Number of channels on the PCA9685 board.
            names (list): A list of names for the servo motors.
            pins (list): A list of pins the servo motors are connected to.
            
        Methods:
            setAngles(angles): Sets the angles of the servo motors.
            stopServo(channel): Stops a specific servo motor.
            setAngle(channel, angle): Sets the angle of a specific servo motor.
            stopServos(): Stops all servo motors.
    """
    def __init__(self, channels, names: list, pins: list):
        self.kit = ServoKit(channels=channels)
        self.names = names
        self.pins = pins

        self._coef = 100

        self.lastAngles = [0] * len(names)

    def setAngles(self, angles: list):
        """
        Sets the goal angles of the servo motors.

        Parameters:
            angles (list): A list of goal angles in degrees.
        """
        for i in range(len(angles)):
            self.kit.servo[i].angle = angles[i]
            self.lastAngles[i] = angles[i]
            
    def setOuterAngles(self, angles: list):
        """
        Sets the goal angles of the outer servo motors.

        Parameters:
            angles (list): A list of goal angles in degrees.
        """

        self.kit.servo[2].angle = angles[0]
        self.kit.servo[3].angle = angles[1]

        self.lastAngles[2] = angles[0]
        self.lastAngles[3] = angles[1]
    
    def setPlankPusherAngles(self, angles: list):
        """
        Sets the goal angles of the plank pusher servo motors.

        Parameters:
            angles (list): A list of goal angles in degrees.
        """
        self.kit.servo[4].angle = angles[0]
        self.kit.servo[5].angle = angles[1]
        
        self.lastAngles[4] = angles[0]
        self.lastAngles[5] = angles[1]
        
    def setBannerDeployerAngle(self, angle: int):
        self.kit.servo[7].angle = angle
        
        self.lastAngles[7] = angle

    def stopServo(self, channel: int):
        """
        Stops a specific servo motor.

        Parameters:
            channel (int): The channel number of the servo motor.
        """
        self.kit.servo[channel].angle = None

    def setAngle(self, name: str, angle: int):
        """
        Sets the goal angle of a specific servo motor.

        Parameters:
            name (int): The channel number of the servo motor.
            angle (int): The goal angle in degrees.
        """
        for i in range(len(self.names)):
            if self.names[i] == name:
                self.kit.servo[self.pins[i]].angle = angle

    def stopServos(self):
        """
        Stops all servo motors.
        """
        for i in range(16):
            self.kit.servo[i].angle = None

    def stopOuterServos(self):
        """
        Stops all outer servo motors.
        """
        for i in range(2, 4):
            self.kit.servo[i].angle = None

    def computeTimeNeeded(self, angles: list[int], servos: str) -> float:
        """ Computes the time needed for all servos to reach the specified angles."""
        diff_angles = []

        if servos == "all":
            # For all servos, compare with all last angles
            diff_angles = [abs(angles[i] - self.lastAngles[i]) for i in range(len(angles))]

        elif servos == "outer":
            # For outer servos (indexes 2,3), compare the passed angles[0] and angles[1] with lastAngles[2] and lastAngles[3]
            diff_angles = [abs(angles[0] - self.lastAngles[2]), abs(angles[1] - self.lastAngles[3])]

        elif servos == "plankPushers":
            # For plank pushers (indexes 4,5), compare the passed angles[0] and angles[1] with lastAngles[4] and lastAngles[5]
            diff_angles = [abs(angles[0] - self.lastAngles[4]), abs(angles[1] - self.lastAngles[5])]

        elif servos == "hinge":
            # For hinge (index 6), compare passed angle with lastAngles[6]
            diff_angles = [abs(angles[0] - self.lastAngles[6])]

        elif servos == "bannerDeployer":
            # For banner deployer (index 7), compare passed angle with lastAngles[7]
            diff_angles = [abs(angles[0] - self.lastAngles[7])]

        # Avoid div by zero in case _coef is 0 
        if not diff_angles or self._coef == 0:
            return 0.1  # Minimum execution time

        max_angle = max(diff_angles)
        time_needed = max_angle / self._coef

        # Add a minimum time to ensure execution completes
        return max(time_needed, 0.1)

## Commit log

2024-10-22 Update '#include <Arduino.h>' placement
2024-10-22 Added IR line following & class implementation of sensors
2024-11-04 Fix motors/sensors direction
2024-11-04 Update distance calculation in UltrasonicSensor to use speed of sound in cm/s
2024-11-06 Convert MotorControl to a class
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2024-12-09 Move redundent if clause before state switch in `FSM_dev`
2024-12-13 Fix initial wrong obstacle detection
    [FSM_dev.cpp, main.cpp]
2024-12-14 Add `SIMA2` folder for Arduino IDE
2024-12-16 Fixed Star FSM + added 3rd IR sensor
    [FSM_Star.cpp, FSM_Star.h, SIMA2.ino]
2024-12-17 Changed superstar + motor speed
2024-12-17 Added celebration phase and implemented leds and servomotors
2024-12-17 changed the servo pin
2024-12-21 Fix old slight problems
    [FSM_Star.cpp, FSM_Star.h, FSM_dev.cpp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]
2024-12-21 Fixed last problems for superstar
    [FSM_Star.cpp, FSM_Star.h, SIMA2.ino]
2024-12-21 Add `arduino.json` to .gitignore
2025-02-07 Fix celebration
    Use time instead of while
    [FSM_Groupie.cpp, FSM_Groupie.h, FSM_Star.cpp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]
2025-02-08 Separate software homework & current SIMA code in separate folders
2025-02-08 Shortened `checkObstacle` if condition in FSM
    [FSM_Groupie.cpp, FSM_Star.cpp]
2025-02-08 Fix constructor parameters formatting
    [FSM_Groupie.cpp, FSM_Star.cpp]
2025-02-08 Fix FSM documentation
    Removed docs in .cpp & add missing parameters in constructor
    [FSM_Groupie.cpp, FSM_Groupie.h, FSM_Star.h]
2025-02-08 Updated `followLine` logic to 2 IR sensors
2025-02-08 Removed center IR sensor
    Updated groupie FSM line following to basic 2 IR sensors
2025-02-08 Fix FSMs constructors initialization
    [FSM_Groupie.cpp, FSM_Star.cpp]
2025-02-08 Fix FSM constructor parameters documentation
    [FSM_Groupie.h, FSM_Star.h]
2025-02-09 Add `setRotationSpeed` to `MotorControl`
2025-02-14 Modified Motor to only test 1 motor
2025-02-15 Fix PAMI celebration servo position
    [FSM_Groupie.cpp, FSM_Star.cpp, SIMA.ino]
2025-02-21 Implement motor control prototype
2025-02-21 added robot code to controle both motor
2025-02-21 Added some test codes for the motors
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2025-02-24 Implement MotorsControl.py and rename bigMotor.py
2025-02-25 Add motors pins to `config.py`
2025-02-25 Move motors to /hardware directory
2025-02-25 Add motors pins to robot.py
2025-02-25 Fix relative import in `motorsControl.py`
    [motorsControl.py]
2025-02-26 Add temp motors enable pins in `config.py`
2025-02-27 Add stepper motor test script with speed control and clockwise rotation
2025-02-27 Add ultrasonic sensor integration + Add rotate state in FSM execution
2025-02-27 Fix Superstar edge time & rotation speed
    [FSM_Star.h]
2025-02-28 ImplementServoMotor Control & tests + Modify ultrasonic sensors
2025-02-28 Add Magnetic Sensor class
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2025-03-10 Implement Claw Control in the FSM
2025-03-10 Correct import module error
    [servoControl.py]
2025-03-10 Add type annotations to ultrasonic sensor
2025-03-10 Add ultrasonic sensor position & pins
2025-03-11 Add reedSwitch class for magnetic switch functionality
2025-03-11 Refactor ultrasonic sensor classes & add controller to `Robot` class
2025-03-11 Made motors stop when in `AvoidObstacleState`
2025-03-12 Implement state switching when obstacle detected and cleared
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2025-03-14 change base pwm values
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2025-03-16 Implement Adafruit Servo Controller + Replace old Servo Control
    [adafruitServoController.py, config.py, robot.py]
2025-03-16 Remove misleading unused test files
    motor_test.py, reedSwitch_test.py, robot_test.py, stepper_test.py
2025-03-16 Remove python 3.10 tests in big_bot_tests.yml
    Raspberry Pi 4 default Python version is 3.11 and 3.12 has also been installed.
2025-03-18 Add pins of I2C for clarification
2025-03-21 Add `.coveragerc` config file
    The config file add coverage functionalities:
    - Keeping track of all if condition possibilities
    - Not covering tests code
    - Excluding TYPE_CHECKING
2025-03-23 [documentation] Added the .STL and .STEP files of the bots and .md files to describe the components we used until 23/03/2025
2025-03-24 removed large .STEP and .STL files from the 3D_design directories
2025-03-24 Re-added .STEP and .STL files using Git LFS
    [Rouge v34.step, assembly_super_star.step, front_chariot_big_bot.step]
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2025-03-26 Finish implementation I2C claws
2025-03-28 Add getters/setters for various `UltrasonicSensor` parameters
    Also changed the returned distance unit from meters to centimeters
2025-03-28 Fix US pins errors & add defensive errors handling
    [ultrasonicController.py]
2025-03-28 Replace US sensor instantiation in `UltrasonicController` constructor by `add_sensor()`
    [robot.py, ultrasonicController.py]
2025-03-28 Add OBSTACLE_PRESENT to USEvent enum and update obstacle detection logic in UltrasonicController & FSM
2025-03-28 Implement robot action when obstacle present for too long
    [config.py]
2025-03-28 Create initial tests for UltrasonicController
2025-03-28 Add back the enable motor pins & Correct small error in collectStates
    [bigMotor.py, motorsControl.py, robot.py]
2025-03-28 Add adaptative Superstar motors rotation speed & adjust params for sprint
2025-03-28 Complete 100% test coverage for `UltrasonicController`
2025-04-01 Test speed of motors
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2025-04-03 Add import error protection caused by OS platform
    [lcd.py]
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2025-04-06 Refines LCD type description and score range
    Updates display docstring to clarify LCD 2004 specs
    Restricts score value to between 0 and 120 to avoid wrong inputs
    [lcd.py]
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2025-04-07 Adds accurate sensor reading method
    Introduces a new function for enhanced sensor reading accuracy via multiple measures.
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2025-04-08 added/modified STEP files for assembly design visulization of 3 kind of bots
    [Rouge v34.step, assembly_super_star.step, big_bot.step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]
2025-04-08 add stl files for groupie
    [arduino_holder_isolator.step, battery_holder.step, carrosserie.step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]
2025-04-08 add stl files for super star
    [capot_cover.step, carrosserie.step, emergency_button_holder.step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]
2025-04-08 add stl files for Big Bot
    [caster_holder.stl, center_claw.stl, foldable_fork.stl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]
2025-04-08 Fix groupies zone turn duration for yellow side
    [FSM_Groupie.h, SIMA.ino]
2025-04-09 Uncomment magnetic start to start the pami correctly
    [FSM_Groupie.cpp]
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2025-04-10 Adapt `StepperMotor` class to hardware limitations
    Limit step delay to 2 miliseconds, catch ValueError raised when limit switches are not connected, and use on() & off() methods instead of device value
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2025-04-11 Update code to move claws at the end
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2025-04-11 Initial work on dual ultrasonic implementation This configuration works and enable us to detect on wider range obstacles
2025-04-11 Setup switch to choose the beginning area side
2025-04-13 Mody ultrasonic test file to add new sensors functions
2025-04-14 Add enable and Disable sensors command to improve code readability
2025-04-14 Modify code logic to not loop through every sensors
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2025-04-15 Update servo commands to get use use int directly instead of lists
2025-04-15 initial commit : groupies and superstar behave correctly without cans on the side of the way
    [FSM_Groupie.cpp, FSM_Groupie.h, FSM_Star.cpp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]
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2025-04-15 Update ultrasonic sensors command time + sequence to test them
2025-04-15 Fix ultrasonic deactivation for cans & groupie rotation
    [FSM_Groupie.cpp, FSM_Groupie.h]
2025-04-16 Add sequences + Tweak config + Tests stepper
2025-04-17 Reduce superstar edge stop time to work with fully charged battery
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2025-04-21 Adapt final competition SIMA values with charged battery
2025-04-25 Add error & movement logging
    [robot.py]
